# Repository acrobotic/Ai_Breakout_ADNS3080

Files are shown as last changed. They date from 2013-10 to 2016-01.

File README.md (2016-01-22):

####Currently under development!

Overview
---
This repository includes the Eagle design files (schematics and layout) for our [ADNS3080 Brekout Board][1]. The ADNS3080 is an optical
mouse sensor with a 30x30 pixel resolution, 2000--6400 fps update rate, and SPI interface.

This breakout board provides the necessary circuitry to communicate with the sensor using a microcontroller via SPI (5V).  The board uses 
.1" spacing for easy mounting on a solderless breadboard. For more info on how to use the ADNS3080 optical mouse sensor for detecting optic flow please visit:
[http://learn.acrobotic.com/ADNS3080][2]

Product page
---
Please consider buying products from Acrobotic to help fund future Open-Source projects like this! We'll always put our best effort in every project, and release all our design files and code for you to use.

[Tutorials, technical details, and more information about this product can be found here: http://acrobotic.com/catalog/product/view/id/66][1]

We also [carry the standalone ADNS3080 chip in our store!][3]

License Information
---

All contents of this repository are licensed under a [Creative Commons Attribution-ShareAlike 3.0 Unported License](http://creativecommons.org/licenses/by-sa/3.0/).



[1]: http://acrobotic.com/catalog/product/view/id/66 "ADNS3080 Optical Mouse Sensor Breakout Board"
[2]: http://learn.acrobotic.com/ADNS3080 "Acrobotic ADNS3080 Tutorial"
[3]: http://acrobotic.com/catalog/product/view/id/65 "ADNS3080 Optical Mouses Sensor"

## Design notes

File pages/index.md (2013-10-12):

---
layout: page
title: Ai Breakout ADNS3080
tagline: Board design files and example firmware for an ADNS3080 breakout board.
github_project: Ai_Breakout_ADNS3080
github_user_url: https://github.com/acrobotic
---
{% include JB/setup %}
{% include INCLUDE.md %}

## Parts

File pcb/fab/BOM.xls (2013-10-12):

Ai Breakout ADNS3080 – BOM
Cisco Zabala (x1sc0@acrobotic.com) last updated: 12.10.2013
Manufacturer | Manuf. Part Number | Vendor | Vendor Part Number | Type | Designator | Qty | Description | Case | SMD, BGA, LCC, OR TH | Notes
Stackpole Electronics Inc | RMCF0603JT10K0 | Digi-Key | RMCF0603JT10K0CT-ND | Resistors | R1, R3 | 2 | RES 10K OHM 1/10W 5% 0603 | 0603 | SMD
Stackpole Electronics Inc | RMCF0603JT20K0 | Digi-Key | RMCF0603JT20K0CT-ND | Resistors | R2, R8 | 2 | RES 20K OHM 1/10W 5% 0603 | 0603 | SMD
Stackpole Electronics Inc | RMCF0603JT1K00 | Digi-Key | RMCF0603JT1K00CT-ND | Resistors | R4, R5, R6, R7, R9 | 5 | RES 1K OHM 1/10W 5% 0603 | 0603 | SMD
Yageo | CC0603ZRY5V7BB105 | Digi-Key | 311-1372-1-ND | Capacitors | C1, C5 | 2 | CAP CER 1UF 16V Y5V 0603 | 0603 | SMD
Yageo | CC0603ZRY5V6BB225 | Digi-Key | 311-1450-1-ND |  | C2 | 1 | CAP CER 2.2UF 10V Y5V 0603 | 0603 | SMD
Yageo | CC0603ZRY5V9BB104 | Digi-Key | 311-1343-1-ND |  | C3, C4 | 2 | CAP CER 0.1UF 50V Y5V 0603 | 0603 | SMD
OSRAM | LB Q39E-N1P1-35-1 | Digi-Key | 475-2815-1-ND | LEDs | ON | 1 | LED CHIPLED BLUE 470NM 0603 SMD | 0603 | SMD
Vishay | VS-MBRA140TRPBF | Digi-Key | VS-MBRA140TRPBFCT-ND | Diodes | D1 | 1 | DIODE SCHOTTKY 40V 1A DO214AC | DO-214AC | SMD
Murata | CSTCW24M0X53-R0 | Digi-Key | 490-1205-1-ND | Crystals | XL1 | 1 | CER RESONATOR 24.0MHZ SMD | 2.5mm x 2.0mm | SMD
Micrel Inc | MIC5205-3.3YM5 TR | Digi-Key | 576-1259-1-ND | ICs | U1 | 1 | IC REG LDO 3.3V 0.15A SOT23-5 | SOT-23-5 | SMD
 |  | Acrobotic | CHP-00003 |  | U2 | 1 | Optical Mouse Sensor ADNS3080 |  | TH
Sullins Connector Solutions | PPPC101LGBN-RC | Digi-Key | S5485-ND | Connectors | J1 | 1 | CONN FEMALE 10POS .100" R/A GOLD |  | TH
 |  | Acrobotic | OPT-00001 | Lens | - | 1 | 8 mm Lens, 45 deg FOV w/ M12x0.5 Mount | - | -

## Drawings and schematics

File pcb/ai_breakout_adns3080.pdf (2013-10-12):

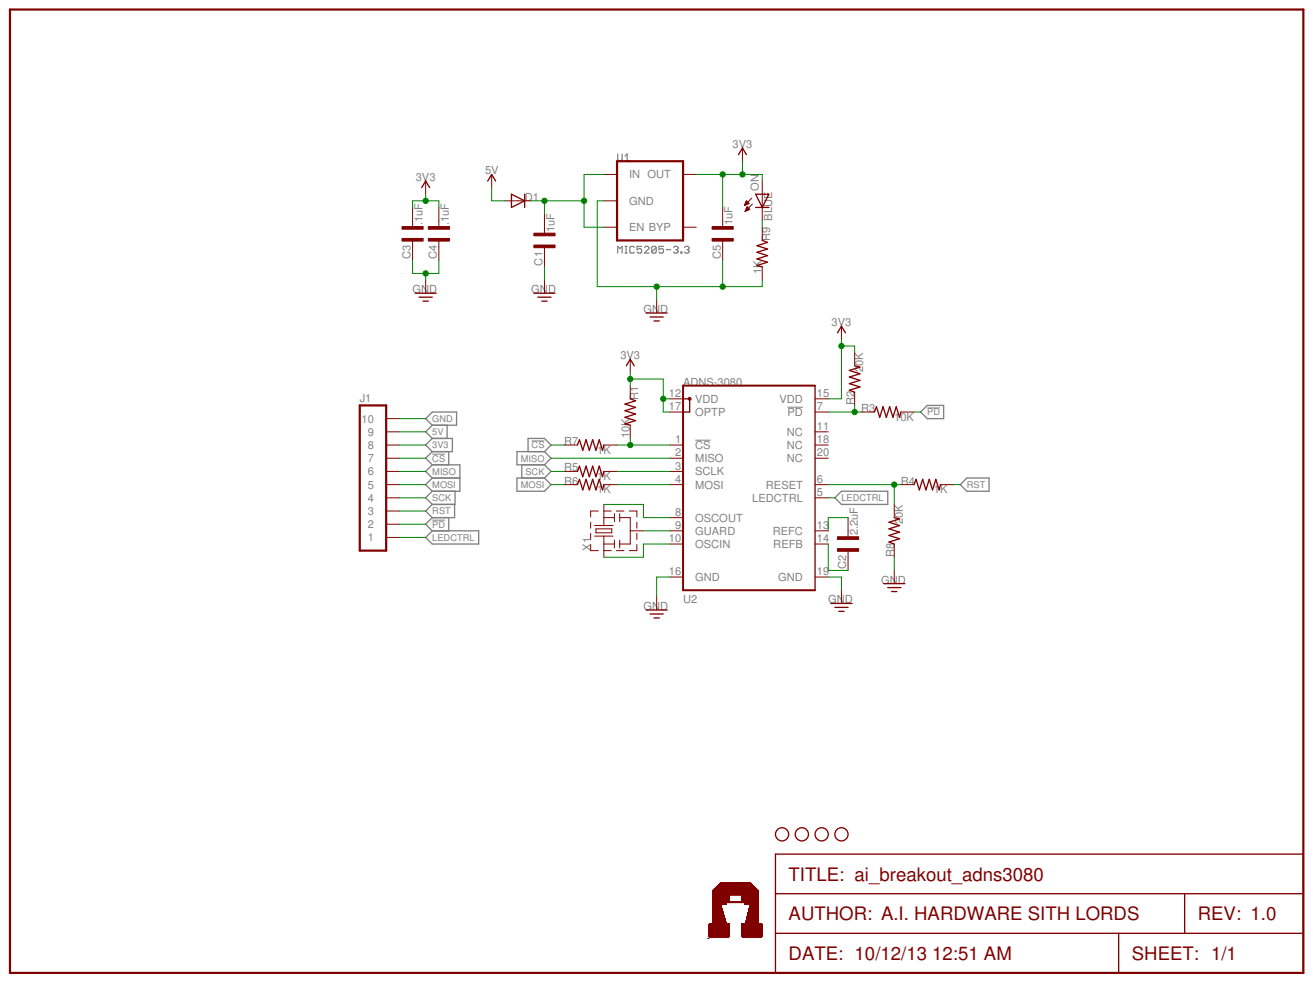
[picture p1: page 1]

AUTHOR: A.I. HARDWARE SITH LORDS | REV: 1.0
DATE: 10/12/13 12:51 AM | SHEET: 1/1

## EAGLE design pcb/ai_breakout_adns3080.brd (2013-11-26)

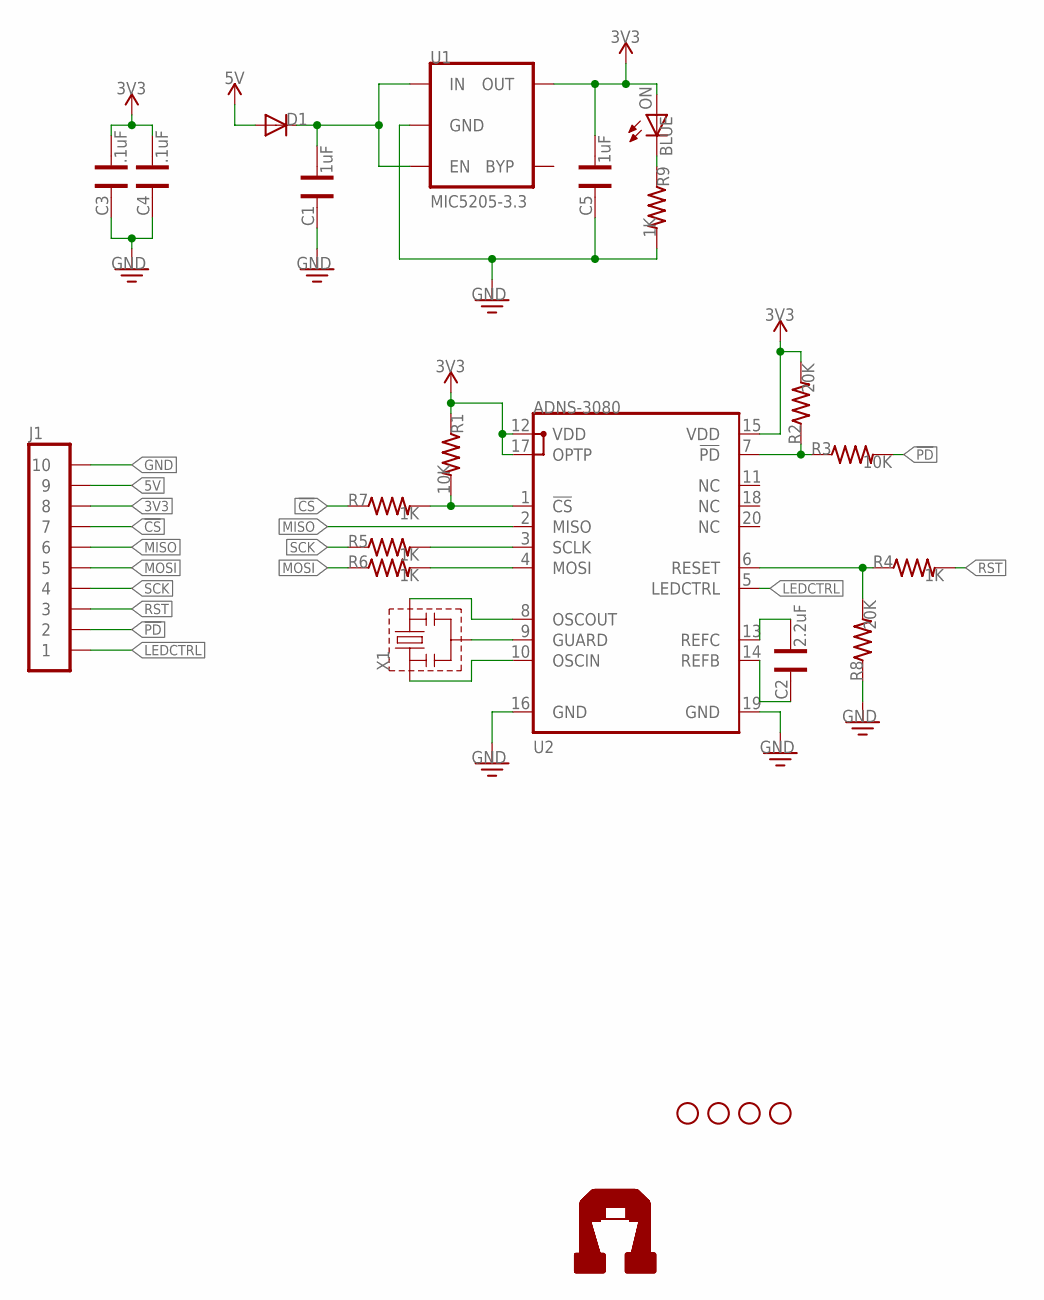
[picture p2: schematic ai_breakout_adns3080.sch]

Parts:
C1, C5: 1uF; CAP-0603
C2: 2.2uF; CAP-0603
C3, C4: .1uF; CAP-0603
D1: DIODESMA-403D; SMA-403D
J1: 1X10
ON: BLUE; LED-0603
R1, R3: 10K; RES-0603
R2, R8: 20K; RES-0603
R4, R5, R6, R7, R9: 1K; RES-0603
STANDOFF1, STANDOFF2, STANDOFF3, STANDOFF4: STAND-OFF
U1: MIC5205-3.3; SOT23-5
U2: ADNS-3080
U$2, U$3: AI-LOGOM; AI-LOGO-M
X1: RESON025X020; RESON-SMD-025X020

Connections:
3V3: C3.1, C4.1, C5.1, J1.8, ON.A, R1.1, R2.2, U1.5 (OUT), U2.12 (VDD), U2.15 (VDD), U2.17 (OPTP)
5V: D1.A, J1.9
!CS: J1.7, R7.1
!PD: J1.2, R3.2
GND: C1.2, C3.2, C4.2, C5.2, J1.10, R8.1, R9.2, U1.2 (GND), U2.16 (GND), U2.19 (GND)
LEDCTRL: J1.1, U2.5 (LEDCTRL)
MISO: J1.6, U2.2 (MISO)
MOSI: J1.5, R6.1
unnamed: C1.1, D1.C, U1.1 (IN), U1.3 (EN)
unnamed: U2.9 (GUARD), X1.2
unnamed: U2.8 (OSCOUT), X1.3
unnamed: R1.2, R7.2, U2.1 (!CS)
unnamed: R5.2, U2.3 (SCLK)
unnamed: U2.10 (OSCIN), X1.1
unnamed: R2.1, R3.1, U2.7 (!PD)
unnamed: R6.2, U2.4 (MOSI)
unnamed: R4.1, R8.2, U2.6 (RESET)
unnamed: C2.1, U2.13 (REFC)
unnamed: C2.2, U2.14 (REFB)
unnamed: ON.C, R9.1
RST: J1.3, R4.2
SCK: J1.4, R5.1

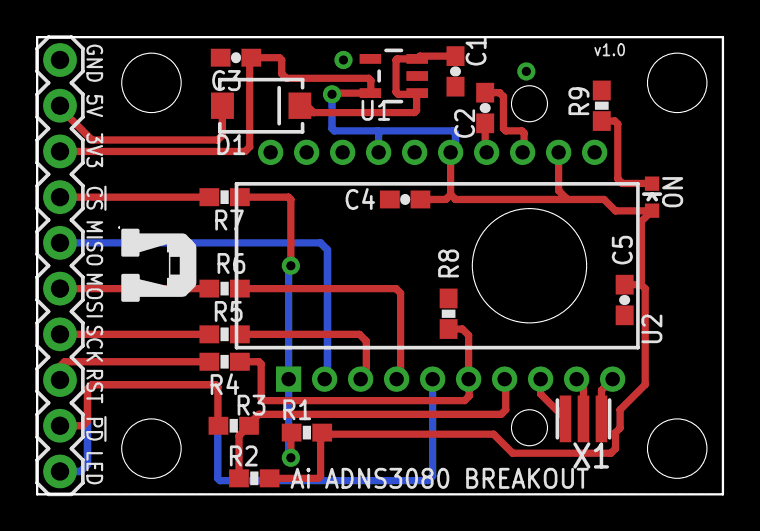
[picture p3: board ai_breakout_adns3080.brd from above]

Board: 2 copper layers, 38.1 x 25.4 mm, 26 parts (1 on the bottom side), 22 nets.

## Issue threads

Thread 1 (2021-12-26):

Unable to access links in README

emmapaczkowski, 2021-12-26:
Hello,

I was excited to come across your repo as I am trying to build an optical mouse using the ADNS3080 sensor. I was hoping to take a look at the contents of the links you added in the readme, however, it looks like they no longer exist? I was wondering if the content has moved somewhere else and if so if you could point me to where I could find it?

Thank you!
Emma

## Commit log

2013-09-22 changes to the silkscreen. added gerbers.
    [ai_breakout_adns3080.brd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]
2013-10-12 Revised version. Finished BOM.
    [BOM.xls, ai_breakout_adns3080.brd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]
2013-10-12 Modified part number in BOM
    [BOM.xls]
2013-11-26 updating to use the latest libraries
    [ai_breakout_adns3080.brd, ai_breakout_adns3080.sch]
